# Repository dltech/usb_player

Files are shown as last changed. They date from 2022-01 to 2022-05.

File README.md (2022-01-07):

# usb_player
simple USB SD mp3 player based on stm32 MCU\
TODO:\
schematic (OK)\
board\
register defs (OK)\
RCC (OK)\
I2S PCM1754 sound out\
lm4811 power regul (OK)\
ADC sound in\
SDIO\
FAT32\
MP3 decoder\
SPI\
CC1101 4FSK\
speex build\
OTG FS USB FLASH (sd adapter)\
OTG FS USB FLASH FAT32 HOST\
STM32 DAC sound output

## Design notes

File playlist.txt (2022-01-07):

13:55:
Evanescence - Everybody's Fool
13:50:
HUDBA PRAHA - MAMA TATA
13:46:
Awolnation - Sail
13:42:
Nickelback - How You Remind Me
13:40:
Cranberries - Salvation
13:35:
Bon Jovi - Runaway
13:32:
Liam Gallagher - The River
13:27:
ZZ Top - Sharp Dressed Man (live)
13:22:
R.E.M. - Drive
13:17:
Iron Maiden - The Writing On The Wall
13:13:
TRI SESTRY - DO KOTLE NA FOTBAL
13:09:
Papa_Roach - Periscope
13:05:
Hollywood Undead - Day Of The Dead
13:02:
Rammstein - Wo Bist Du
12:56:
Republica - Ready To Go
12:52:
Faith No More - Last Cup Of Sorrow
12:48:
Red Hot Chili Peppers - Aeroplane
12:44:
LUCIE - OHEN
12:37:
Metallica - Until It Sleeps
12:33:
Hole - Malibu
12:29:
Smashing Pumpkins - Tonight,Tonight (live)
12:26:
Green Day - Redundant
12:22:
Ugly Kid Joe - Everything About You
12:16:
LOU FANANEK HAGEN & ALKEHOL - DEJVICE
12:12:
Alice Cooper - It's Me
12:07:
Marilyn Manson - Sweet Dreams
12:04:
Cranberries - Promises
11:56:
Apocalyptica - Life Burns!
11:52:
IMODIUM - VALERIE
11:48:
J.A.R. - KNIHOVNICKA
11:42:
Bon Jovi - You Give Love A Bad Name
11:38:
Red Sun Rising - Deathwish
11:31:
Foo Fighters - Everlong (live)
11:26:
Sting - All This Time
11:23:
Rise Against - Talking To Ourselves
11:16:
Soundgarden - Black Hole Sun
11:11:
Soundgarden - Black Rain
11:08:
WOHNOUT - BARBIE SONG
11:04:
Lenny Kravitz - Bring It On
10:56:
Aerosmith - Girls Of Summer
10:53:
Rammstein - Du Hast
10:49:
Red Hot Chili Peppers - Look Around
10:46:
Counting Crows - Accidentally In Love
10:40:
Metallica - Wherever I May Roam
10:35:
ZZ Top - La Grande
10:31:
P.O.D. - Youth Of The Nation
10:25:
Gossip - Standing In The Way Of Control (Live)
10:21:
Puff Daddy & Jimmy Page - Come With Me
10:19:
Wolfmother - Fellin Love
10:12:
Muse - Resistance
10:09:
Sabaton - To Hell And Back
10:05:
AC/DC - Hard As A Rock
10:02:
TRI SESTRY - PUMPA
09:52:
Offspring - Original Prankster
09:48:
Cranberries - Free To Decide
09:45:
Tarja - No Bitter End
09:42:
Green Day - Holiday
09:37:
Alice Cooper - School's Out
09:33:
Scott Stapp - Gone Too Soon
09:27:
Black Sabbath - Electric Funeral (live)
09:24:
Guano Apes - Lords Of The Boards
09:21:
Sting - Rushing Water
09:15:
VISACI ZAMEK - ZNAMKA PUNKU
09:12:
VISACI ZAMEK - NOTORIKOVA OMLUVA
09:08:
Foster The People - Pumped Up Kicks
09:04:
Rammstein - Haifisch
08:57:
System Of A Down - Lonely Day
08:53:
Nirvana - All Apologies
08:49:
U2 - Beautiful Day
08:46:
KABAT - BRUCE WILLIS
08:40:
Queen - I Want It All
08:36:
Stone Sour - Song # 3
08:31:
Alanis Morissette - Hand In My Pocket (live)
08:25:
R.E.M. - Man On The Moon
08:21:
Danko Jones - Ship of Lies
08:16:
SUPPORT LESBIENS - Sweet Little Something
08:12:
Rise Against - Satellite
08:08:
Lenny Kravitz - Fly Away
08:05:
Linkin Park - Leave Out All The Rest
07:56:
Seether - Remedy
07:54:
Faith No More - Easy....
07:47:
Bon Jovi - Bed Of Roses
07:42:
Clash - Should I Stay Or Should I Go
07:39:
WOHNOUT - MISS MARINGOTKA
07:32:
Avenged Sevenfold - Hail To The King (live)
07:26:
Guns N'Roses - You Could Be Mine
07:22:
Sixx:A.M. - The First 21
07:17:
Blink 182 - I Miss You
07:12:
Alter Bridge - Addicted To Pain
07:08:
Scorpions - White Dove
07:04:
Vanilla Sky - Umbrella
06:55:
Foo Fighters - Best Of You
06:51:
LUCIE - ČERNÍ ANDĚLÉ
06:48:
Placebo - Too Many Friends
06:45:
Offspring - Hit That
06:39:
Sex Pistols - Anarchy In The U.K.
06:35:
IMODIUM - VASEN
06:30:
U2 - Pride (In The Name Of Love) (live)
06:27:
Deaf Heart - Smells Like Cash
06:23:
AC/DC - Are You Ready
06:20:
Maneskin - I Wanna Be Your Slave
06:14:
HIM - Join Me
06:11:
Sabaton - Resist And Bite
06:08:
Bad Religion - Punk Rock Song
06:05:
Red Hot Chili Peppers - Tell Me Baby
05:56:
KABÁT - COLORADO
05:53:
Bon Jovi - Saturday Night Gave Me Sunday Morning
05:49:
Black Veil Brides - Torch
05:45:
Lenny Kravitz - Again
05:40:
Metallica - Whiskey In The Jar
05:35:
Def Leppard - Pour Some Sugar On Me
05:31:
Nickelback - Must Be Nice
05:27:
Jeff Healey Band - Stuck In The Middle With You (live)
05:21:
Guns N'Roses - Knockin' On Heaven's Door
05:18:
WOHNOUT - RAYDA
05:15:
Billy Idol - Rita Hayworth
05:10:
Green Day - Oh Love
05:06:
Aerosmith - Cryin'
05:03:
Bloodhound Gang - Foxtrot Uniform Charlie Kilo
04:55:
Moby - Why Does My Heart Feel So Bad
04:50:
Within Temptation & Tarja - Paradise (What About Us?)
04:47:
Coldplay - People of the Pride
04:42:
My Chemical Romance - Welcome To The Black Parade
04:38:
Sheryl Crow - Everyday Is A Winding Road
04:35:
Jefferson Airplane - Somebody To Love
04:32:
SKWOR - POKRIVENEJ POHLED
04:28:
Korn & Amy Lee - Freak On A Leash (live)
04:22:
Pearl Jam - Alive
04:18:
Placebo - Special Needs
04:16:
Volbeat - Wait A Minute My Girl
04:12:
Disturbed - The Sound Of Silence
04:07:
Ozzy Osbourne - Perry Mason
04:04:
Linkin Park - What I've Done
03:58:
HIM - The Funeral Hearts
03:54:
Garbage - I Think I'm Paranoid
03:51:
Korpiklaani - Rauta
03:47:
You Me At Six - Adrenaline
03:45:
HORKYZE SLIZE - A JA SPROSTA
03:40:
U2 - Staring At The Sun
03:36:
Guns N'Roses - Welcome To The Jungle
03:32:
Rise Against - The Violence
03:30:
Queen - Bicycle Race (live)
03:27:
VLTAVA - MARX,ENGELS,BEATLES
03:21:
Red Hot Chili Peppers - Snow (Hey Oh)
03:16:
Iron Maiden - The Writing On The Wall
03:12:
Foo Fighters - The Feast And The Famine
03:08:
Verve - Sonnet
03:05:
Simple Plan - Shut Up
02:57:
Alanis Morissette - You Oughta Know
02:53:
Shinedown - Cut The Cord
02:48:
Pretty Reckless - Only Love Can Save Me Now
02:45:
Chad Kroeger & Josey Scott - Hero
02:41:
Rammstein - Rammstein
02:37:
Aerosmith - Dream On
02:34:
Alice Cooper - Social Debris
02:27:
Bon Jovi - Keep The Faith (live)
02:23:
Iggy Pop & Kate Pierson - Candy
02:19:
Johnny Cash - Hurt
02:15:
Lee Aaron - C´mon
02:10:
Tarja - Falling Awake
02:07:
WANASTOWI VJECY - BLBA
02:04:
Killers - Somebody Told Me
01:57:
Hinder - Use Me
01:53:
Beck - Loser
01:50:
Halestorm - Amen
01:46:
Garbage - No Gods No Masters
01:42:
SKWOR - POHLEDY STUDENY
01:39:
Pearl Jam - Last Kiss
01:35:
Survivor - Eye Of Tiger
01:31:
Black Veil Brides - The Last One
01:26:
Awolnation - Not Your Fault (live)
01:21:
Scorpions - Wind Of Change
01:17:
Darkness - One Way Ticket
01:14:
Rise Against - Talking To Ourselves
01:11:
Linkin Park - Castle Of Glass
01:08:
KABÁT - LÁĎA
01:04:
Rasmus - No Fear
00:57:
Kid Rock - So Hott
00:51:
Aerosmith - Livin' On The Edge
00:48:
Korn - Rotting In Vain
00:44:
Black Label Society - Set You Free
00:41:
Green Day - American Idiot
00:35:
Oasis - Stand By Me
00:32:
Iron Maiden - Can I Play With Madness
00:28:
Alice Cooper - Paranoiac Personality
00:24:
Inxs - Never Tear Us Apart (live)
00:20:
Nirvana - Lithium
00:15:
U2 - Stuck In A Moment You Can't Get Out
00:13:
Wolfmother - Fellin Love
00:09:
Serj Tankian - Cornucopia
00:05:
Cranberries - When You're Gone
00:02:
VYPSANA FIXA - DEZOLAT

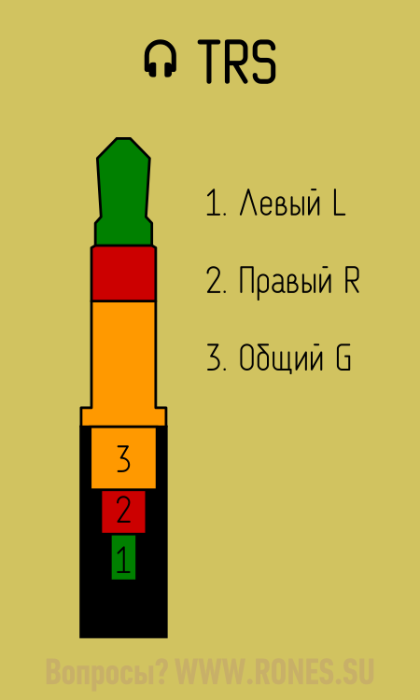
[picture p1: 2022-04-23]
pdf/TRSpinout.png

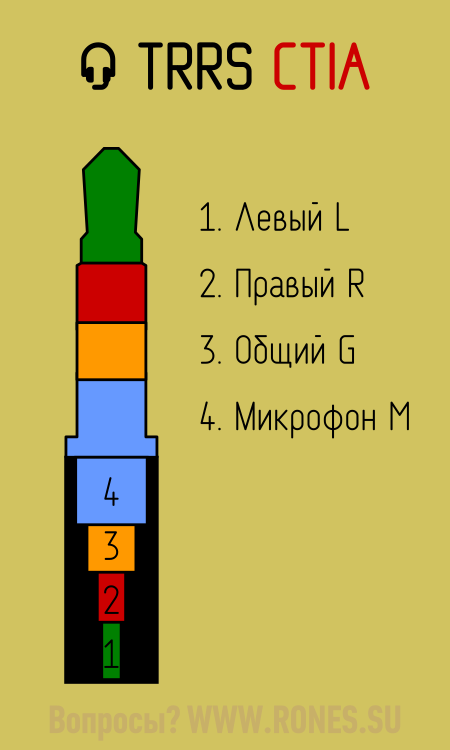
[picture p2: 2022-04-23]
pdf/TRRS_CTIA.png

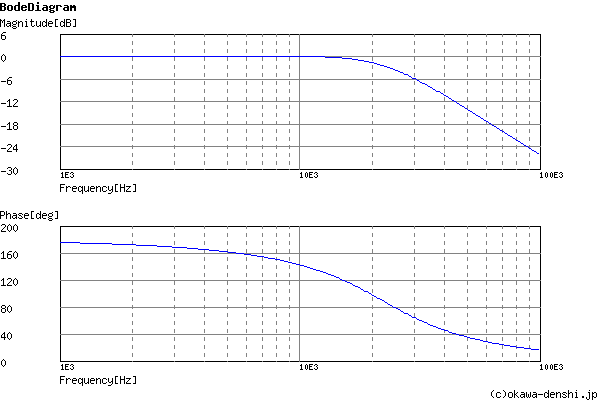
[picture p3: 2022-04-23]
pdf/low_pass.png

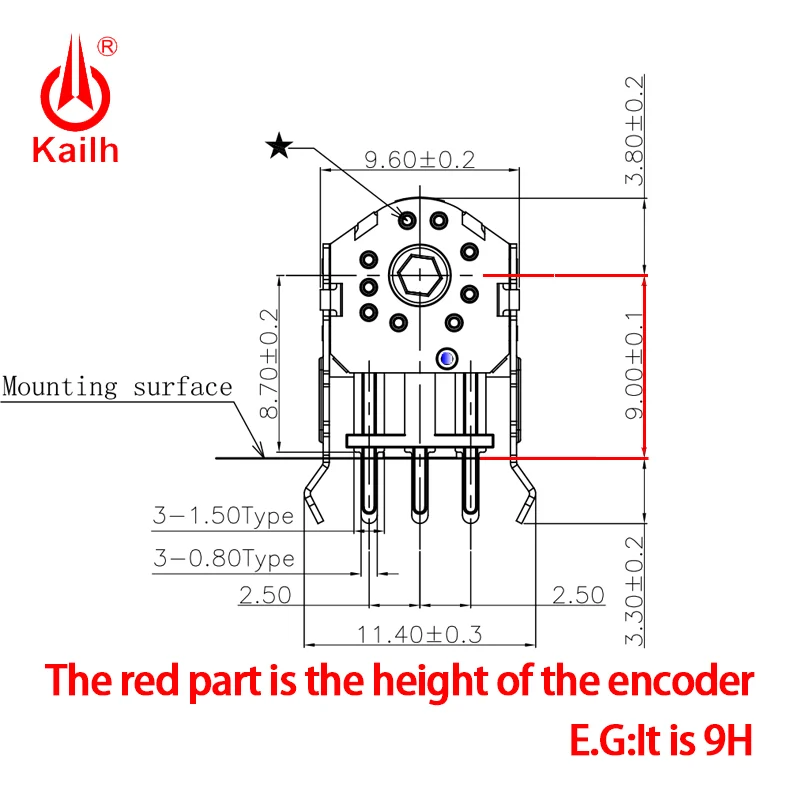
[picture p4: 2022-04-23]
pdf/mouse_encoder.webp

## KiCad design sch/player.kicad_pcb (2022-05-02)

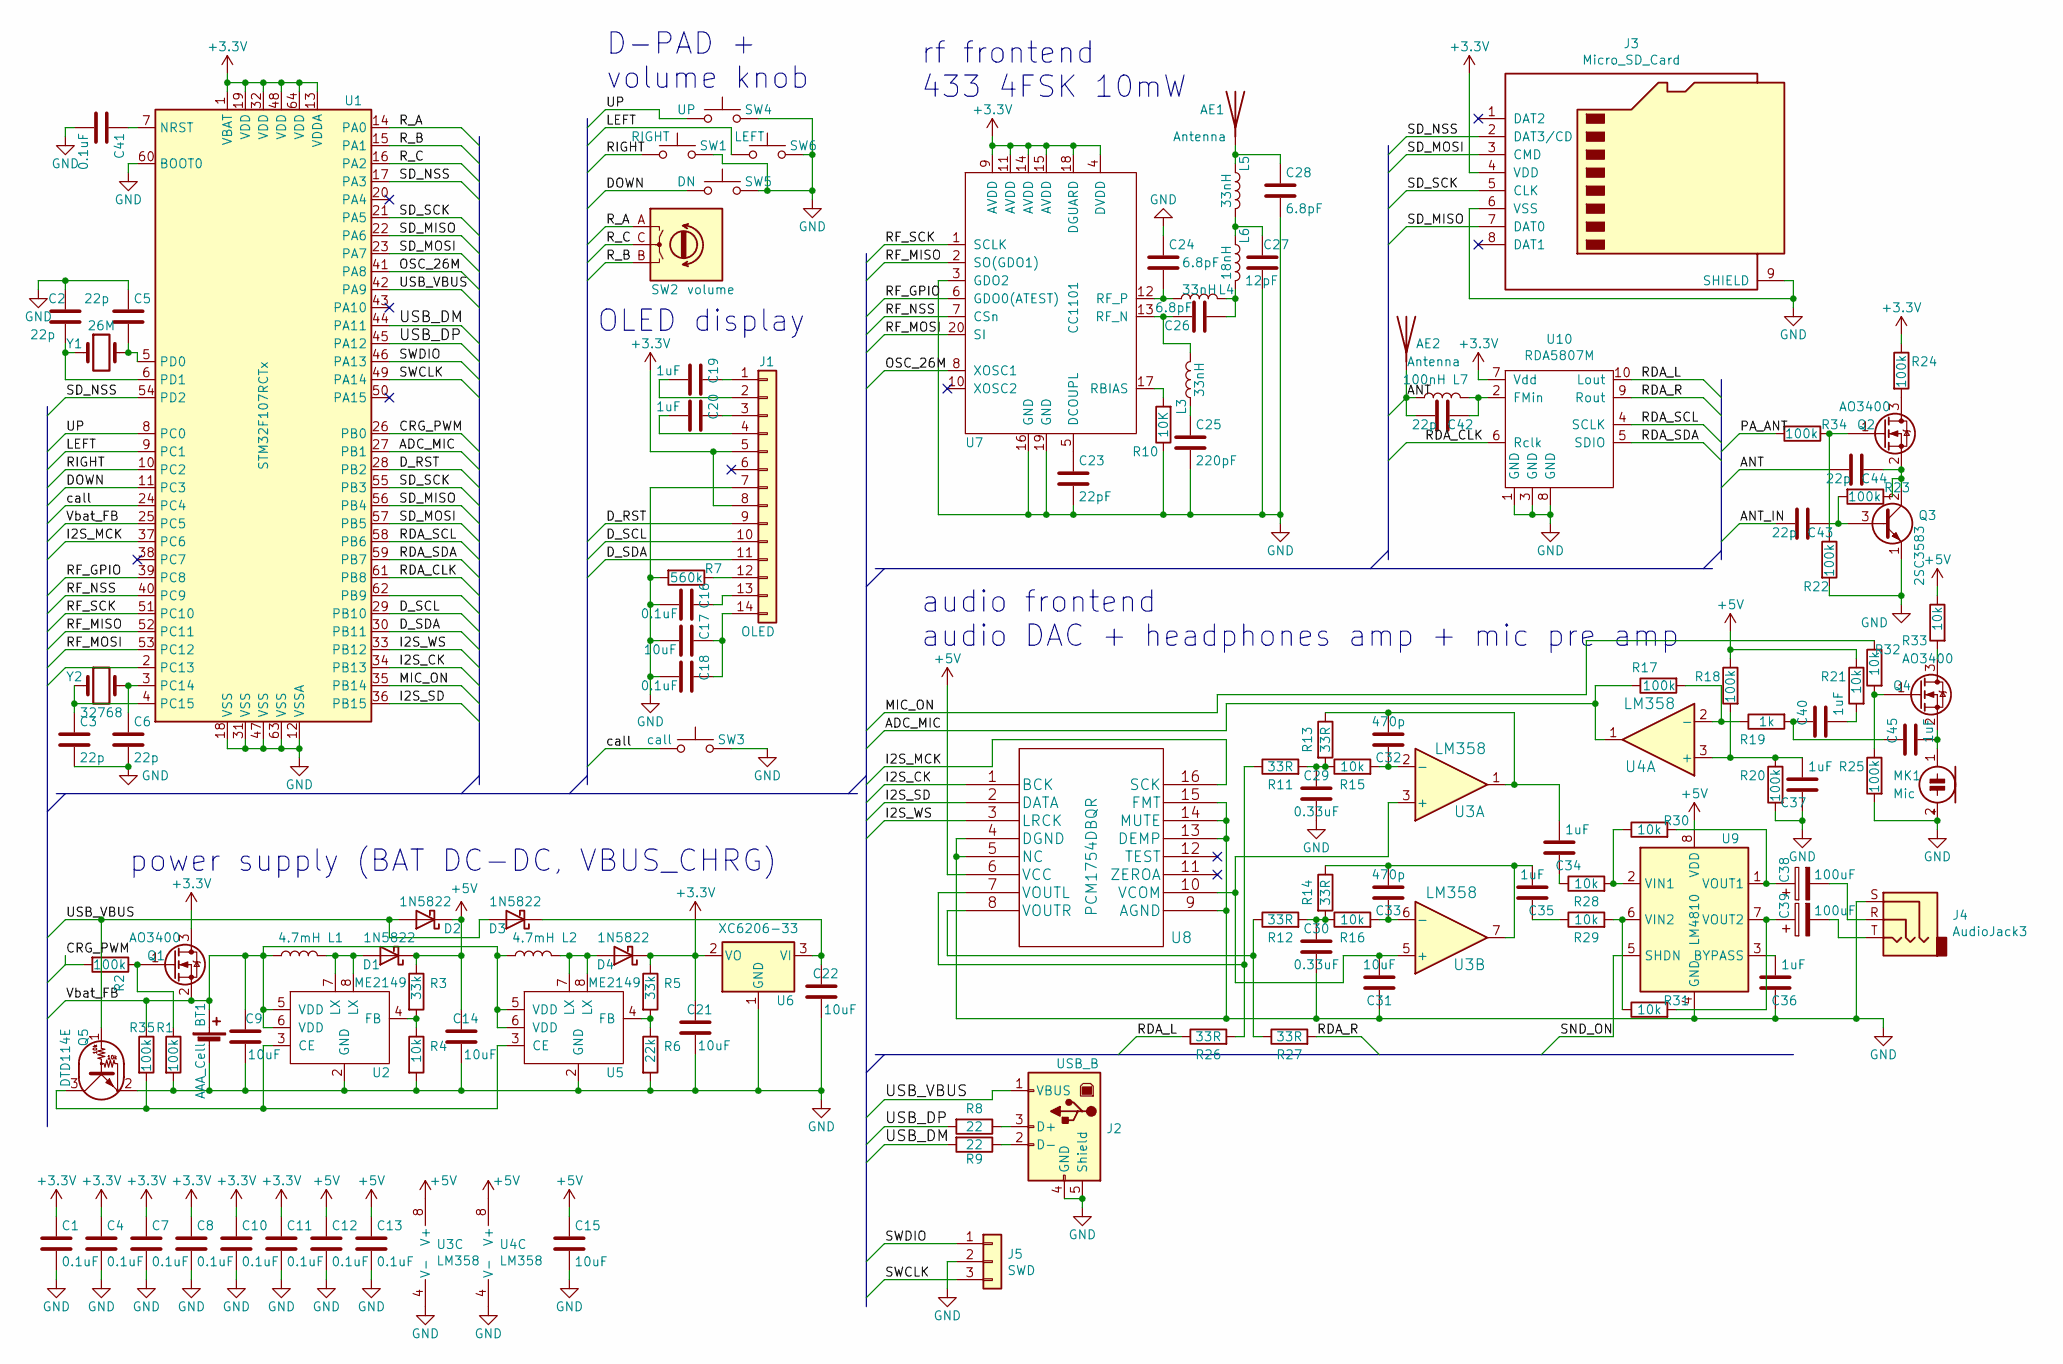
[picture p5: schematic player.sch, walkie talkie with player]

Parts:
AE1, AE2: Antenna; SolderWirePad_1x01_SMD_1x2mm
BT1: AAA_Cell; PinHeader_2x01_P2.54mm_Vertical
C1, C4, C7, C8, C10, C11, C12, C13, C16, C18, C41: 0.1uF; C_0402_1005Metric
C2, C3, C5, C6, C42, C43, C44: 22p; C_0402_1005Metric
C9, C14, C15, C17, C21, C22, C31: 10uF; C_0805_2012Metric
C19, C20, C34, C35, C36, C37, C40, C45: 1uF; C_0805_2012Metric
C23: 22pF; C_0402_1005Metric
C24, C26, C28: 6.8pF; C_0603_1608Metric
C25: 220pF; C_0603_1608Metric
C27: 12pF; C_0603_1608Metric
C29, C30: 0.33uF; C_0603_1608Metric
C32, C33: 470p; C_0603_1608Metric
C38, C39: 100uF; C_1206_3216Metric
D1, D2, D3, D4: 1N5822; D_SMA
J1: OLED; display_14p
J2: USB_B; USB_Micro-B_Molex_47346-0001
J3: Micro_SD_Card; microSD_HC_Hirose_DM3BT-DSF-PEJS
J4: AudioJack3; uefang
J5: SWD; 3WIRE_PADS
L1: 4.7mH; L_7.3x7.3_H4.5
L2: 4.7mH; L_1206_3216Metric
L3, L4, L5: 33nH; L_0603_1608Metric
L6: 18nH; L_0603_1608Metric
L7: 100nH; L_0603_1608Metric
MK1: Mic; CP_Radial_D5.0mm_P2.50mm
Q1, Q2, Q4: AO3400; SOT-23
Q3: 2SC3583; SOT-23
Q5: DTD114E; SOT-23
R1, R2, R20, R22, R23, R24, R25, R34, R35: 100k; R_0402_1005Metric
R3, R5: 33k; R_0805_2012Metric
R4, R15, R16, R21, R28, R29, R30, R31, R32, R33: 10k; R_0402_1005Metric
R6: 22k; R_0805_2012Metric
R7: 560k; R_0805_2012Metric
R8, R9: 22; R_0402_1005Metric
R10: 10K; R_0402_1005Metric
R11, R12, R13, R14, R26, R27: 33R; R_0402_1005Metric
R17, R18: 100k; C_0402_1005Metric
R19: 1k; R_0805_2012Metric
SW1: RIGHT; SW_PUSH_6mm
SW2: volume; mouse_encoder
SW3: call; SW_PUSH_6mm
SW4: UP; SW_PUSH_6mm
SW5: DN; SW_PUSH_6mm
SW6: LEFT; SW_PUSH_6mm
U1: STM32F107RCTx; LQFP-64_10x10mm_P0.5mm
U2, U5: ME2149; SSOP-8_3.9x5.05mm_P1.27mm
U3, U4: LM358; SSOP-8_3.9x5.05mm_P1.27mm
U6: XC6206-33; SOT-23
U7: CC1101; cc1101
U8: PCM1754DBQR; SSOP-16_3.9x4.9mm_P0.635mm
U9: LM4810; TSSOP-8_3x3mm_P0.65mm
U10: RDA5807M; MSOP-10_3x3mm_P0.5mm
Y1: 26M; Crystal_SMD_5032-2Pin_5.0x3.2mm
Y2: 32768; Crystal_SMD_2012-2Pin_2.0x1.2mm

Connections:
+5V: C12.1, C13.1, C14.2, C15.1, D1.1 (K), D2.1 (K), R3.1, R18.1, R21.1, R33.1, U3.8 (V+), U4.8 (V+), U8.6 (VCC), U9.8 (VDD)
/ADC_MIC: R17.1, U1.27 (PB1), U4.1
/ANT: AE2.1, C42.1, C44.1, L7.1
/ANT_IN: C43.1
/CRG_PWM: R2.2, U1.26 (PB0)
/DOWN: SW5.1, U1.11 (PC3)
/D_RST: J1.9, U1.28 (PB2)
/D_SCL: J1.10, U1.29 (PB10)
/D_SDA: J1.11, U1.30 (PB11)
/I2S_CK: U1.34 (PB13), U8.1 (BCK)
/I2S_MCK: U1.37 (PC6), U8.16 (SCK)
/I2S_SD: U1.36 (PB15), U8.2 (DATA)
/I2S_WS: U1.33 (PB12), U8.3 (LRCK)
/LEFT: SW6.1, U1.9 (PC1)
/MIC_ON: R32.1, U1.35 (PB14)
/OSC_26M: U1.41 (PA8), U7.8 (XOSC1)
/PA_ANT: R34.2
/RDA_CLK: U1.61 (PB8), U10.6 (Rclk)
/RDA_L: R26.1, U10.10 (Lout)
/RDA_R: R27.2, U10.9 (Rout)
/RDA_SCL: U1.58 (PB6), U10.4 (SCLK)
/RDA_SDA: U1.59 (PB7), U10.5 (SDIO)
/RF_GPIO: U1.39 (PC8), U7.6 (GDO0(ATEST))
/RF_MISO: U1.52 (PC11), U7.2 (SO(GDO1))
/RF_MOSI: U1.53 (PC12), U7.20 (SI)
/RF_NSS: U1.40 (PC9), U7.7 (CSn)
/RF_SCK: U1.51 (PC10), U7.1 (SCLK)
/RIGHT: SW1.1, U1.10 (PC2)
/R_A: SW2.A, U1.14 (PA0)
/R_B: SW2.B, U1.15 (PA1)
/R_C: SW2.C, U1.16 (PA2)
/SD_MISO: J3.7 (DAT0), U1.22 (PA6), U1.56 (PB4)
/SD_MOSI: J3.3 (CMD), U1.23 (PA7), U1.57 (PB5)
/SD_NSS: J3.2 (DAT3/CD), U1.17 (PA3), U1.54 (PD2)
/SD_SCK: J3.5 (CLK), U1.21 (PA5), U1.55 (PB3)
/SND_ON: U9.5 (SHDN)
/SWCLK: J5.3, U1.49 (PA14)
/SWDIO: J5.1, U1.46 (PA13)
/UP: SW4.1, U1.8 (PC0)
/USB_DM: R9.2, U1.44 (PA11)
/USB_DP: R8.2, U1.45 (PA12)
/USB_VBUS: D2.2 (A), D3.2 (A), J2.1 (VBUS), Q5.1 (B), U1.42 (PA9)
/Vbat_FB: BT1.1 (+), C9.2, L1.1, L2.1, Q1.2 (S), R35.1, U1.25 (PC5), U2.5 (VDD), U2.6 (VDD), U5.5 (VDD), U5.6 (VDD)
/call: SW3.1, U1.24 (PC4)
GND: BT1.2 (-), C1.2, C2.1, C3.2, C4.2, C5.1, C6.2, C7.2, C8.2, C9.1, C10.2, C11.2, C12.2, C13.2, C14.1, C15.2, C16.2, C17.1, C18.2, C21.1, C22.1, C23.2, C24.1, C25.2, C27.2, C28.2, C29.1, C30.1, C31.1, C36.1, C37.1, C41.2, J1.7, J2.4 (GND), J2.5 (Shield), J3.6 (VSS), J3.9 (SHIELD), J4.S, J5.2, MK1.2 (+), Q3.1 (E), Q5.2 (E), R1.2, R4.2, R6.2, R7.2, R10.1, R20.2, R22.2, R25.2, SW1.2, SW3.2, SW4.2, SW5.2, SW6.2, U1.12 (VSSA), U1.18 (VSS), U1.31 (VSS), U1.47 (VSS), U1.60 (BOOT0), U1.63 (VSS), U2.2 (GND), U3.4 (V-), U4.4 (V-), U5.2 (GND), U6.1 (GND), U7.3 (GDO2), U7.16 (GND), U7.19 (GND), U8.4 (DGND), U8.5 (NC), U8.9 (AGND), U8.13 (DEMP), U8.14 (MUTE), U8.15 (FMT), U9.4 (GND), U10.1 (GND), U10.3 (GND), U10.8 (GND)
unnamed: AE1.1, C28.1, L5.1
unnamed: C2.2, U1.6 (PD1), Y1.1
unnamed: C3.1, U1.4 (PC15), Y2.1
unnamed: C5.2, U1.5 (PD0), Y1.2
unnamed: C6.1, U1.3 (PC14), Y2.2
unnamed: C16.1, J1.13
unnamed: C17.2, C18.1, J1.14
unnamed: C19.1, J1.1
unnamed: C19.2, J1.2
unnamed: C20.1, J1.3
unnamed: C20.2, J1.4
unnamed: C23.1, U7.5 (DCOUPL)
unnamed: C24.2, L4.1, U7.12 (RF_P)
unnamed: C25.1, L3.1
unnamed: C26.1, L4.2, L6.2
unnamed: C26.2, L3.2, U7.13 (RF_N)
unnamed: C27.1, L5.2, L6.1
unnamed: C29.2, R11.2, R13.2, R15.1
unnamed: C30.2, R12.2, R14.2, R16.1
unnamed: C31.2, U3.3 (+), U3.5 (+), U8.10 (VCOM)
unnamed: C32.1, R15.2, U3.2 (-)
unnamed: C32.2, C34.2, R13.1, U3.1
unnamed: C33.1, R16.2, U3.6 (-)
unnamed: C33.2, C35.2, R14.1, U3.7
unnamed: C34.1, R28.1
unnamed: C35.1, R29.1
unnamed: C36.2, U9.3 (BYPASS)
unnamed: C37.2, R18.2, R20.1, U4.3 (+)
unnamed: C38.1, R30.2, U9.1 (VOUT1)
unnamed: C38.2, J4.R
unnamed: C39.1, R31.2, U9.7 (VOUT2)
unnamed: C39.2, J4.T
unnamed: C40.1, C45.1, R19.2
unnamed: C40.2, R21.2
unnamed: C41.1, U1.7 (NRST)
unnamed: C42.2, L7.2, U10.2 (FMin)
unnamed: C43.2, Q3.3 (B), R23.2
unnamed: C44.2, Q2.2 (S), Q3.2 (C), R23.1
unnamed: C45.2, MK1.1 (-), Q4.2 (S)
unnamed: D1.2 (A), L1.2, U2.7 (LX), U2.8 (LX)
unnamed: D4.2 (A), L2.2, U5.7 (LX), U5.8 (LX)
unnamed: J1.12, R7.1
unnamed: J2.2 (D-), R9.1
unnamed: J2.3 (D+), R8.1
unnamed: Q1.1 (G), R1.1, R2.1
unnamed: Q2.1 (G), R22.1, R34.1
unnamed: Q2.3 (D), R24.2
unnamed: Q4.1 (G), R25.1, R32.2
unnamed: Q4.3 (D), R33.2
unnamed: Q5.3 (C), R35.2, U2.3 (CE), U5.3 (CE)
unnamed: R3.2, R4.1, U2.4 (FB)
unnamed: R5.2, R6.1, U5.4 (FB)
unnamed: R10.2, U7.17 (RBIAS)
unnamed: R11.1, R26.2, U8.7 (VOUTL)
unnamed: R12.1, R27.1, U8.8 (VOUTR)
unnamed: R17.2, R19.1, U4.2 (-)
unnamed: R28.2, R30.1, U9.2 (VIN1)
unnamed: R29.2, R31.1, U9.6 (VIN2)

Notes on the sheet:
rf frontend 433 4FSK 10mW
audio frontend audio DAC + headphones amp + mic pre amp
D-PAD + volume knob
OLED display
power supply (BAT DC-DC, VBUS_CHRG)

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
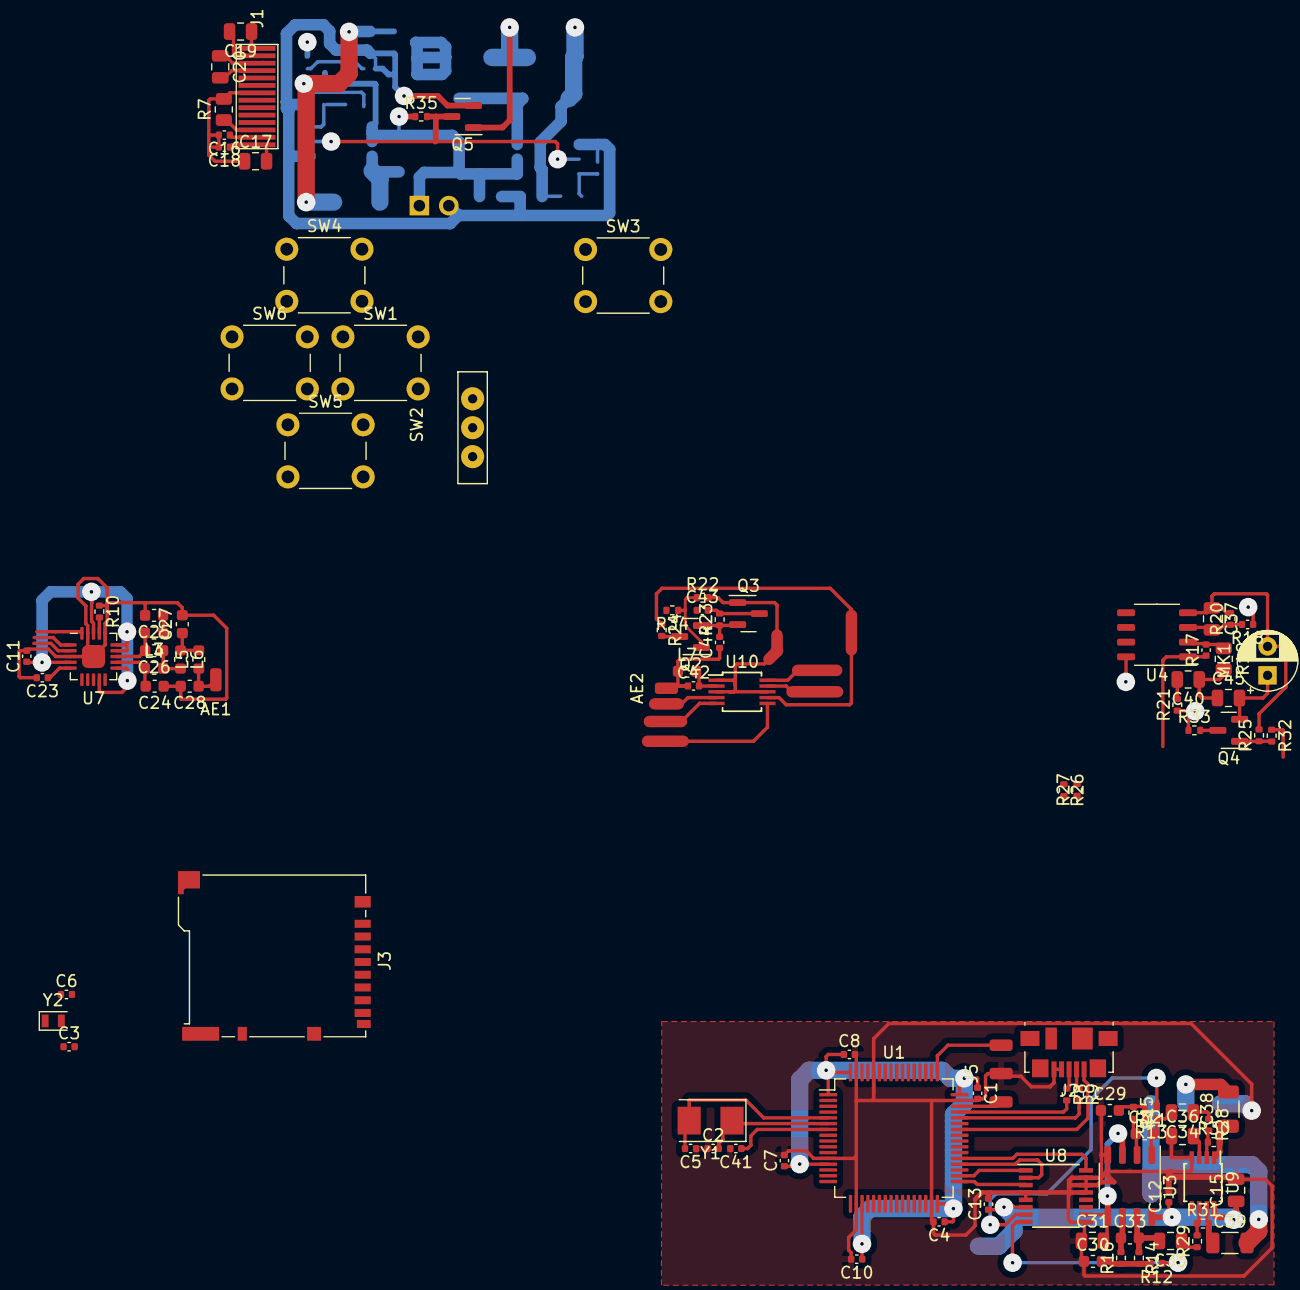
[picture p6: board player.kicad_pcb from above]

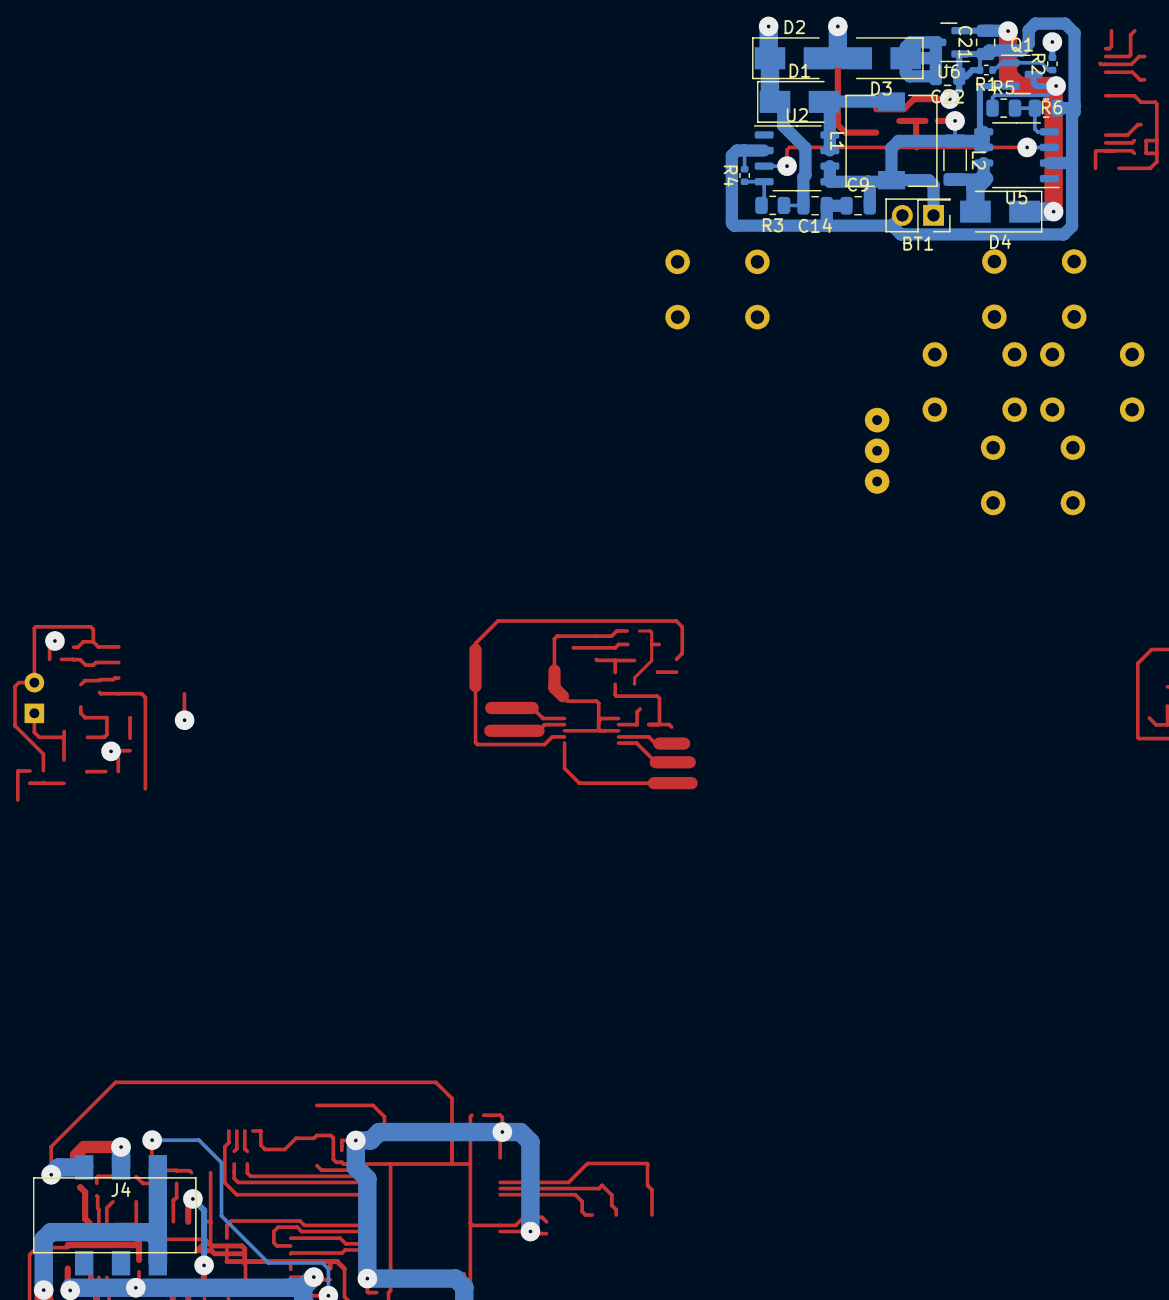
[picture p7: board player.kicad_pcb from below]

Board: 2 copper layers, 123 parts (22 on the bottom side), 102 nets.

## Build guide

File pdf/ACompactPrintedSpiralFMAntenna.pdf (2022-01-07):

See discussions, stats, and author profiles for this publication at: https://www.researchgate.net/publication/277016433
A Compact Printed Spiral FM Antenna (https://www.researchgate.net/publication/277016433_A_Compact_Printed_Spiral_FM_Antenna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)

Conference Paper · July 2015

CITATION
1

READS
4,141

### 4 authors, including:

Some of the authors of this publication are also working on these related projects:

WiFi Communication/Networking View project (https://www.researchgate.net/project/WiFi-Communication-Networking?el=1_x_9&_esc=publicationCoverPdf)

On-chip antenna design, optimization and fabrication in 28nm CMOS technology for 5G communication systems View project (https://www.researchgate.net/project/On-chip-antenna-design-optimization-and-fabrication-in-28nm-CMOS-technology-for-5G-communication-systems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)

Abraham Loutridis (https://www.researchgate.net/profile/Abraham-Loutridis?el=1_x_5&_esc=publicationCoverPdf)
AlpsAlpine Europe

### 15 PUBLICATIONS 71 CITATIONS

SEE PROFILE (https://www.researchgate.net/profile/Abraham-Loutridis?el=1_x_7&_esc=publicationCoverPdf)

Kansheng Yang (https://www.researchgate.net/profile/Kansheng-Yang?el=1_x_5&_esc=publicationCoverPdf)
The Antenna Company Nederland

### 17 PUBLICATIONS 113 CITATIONS

SEE PROFILE (https://www.researchgate.net/profile/Kansheng-Yang?el=1_x_7&_esc=publicationCoverPdf)

M.J. Ammann (https://www.researchgate.net/profile/Mj-Ammann?el=1_x_5&_esc=publicationCoverPdf)
Technological University Dublin - City Campus (https://www.researchgate.net/institution/Technological-University-Dublin-City-Campus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)

295 PUBLICATIONS 5,004 CITATIONS

SEE PROFILE (https://www.researchgate.net/profile/Mj-Ammann?el=1_x_7&_esc=publicationCoverPdf)

All content following this page was uploaded by Abraham Loutridis (https://www.researchgate.net/profile/Abraham-Loutridis?el=1_x_10&_esc=publicationCoverPdf) on 22 May 2015.

The user has requested enhancement of the downloaded file.

1

A Compact Printed Spiral FM Antenna

Abraham Loutridis¹, 2

, Kansheng Yang¹, 2

, Matthias John²

, and Max Ammann¹
1Antenna & HF Research Centre, Dublin Institute of Technology, Dublin 8, Ireland 2CTVR — The Telecommunications Research Centre, Trinity College Dublin, Dublin 2, Ireland

Abstract— In this work,a compact printed spiral monopole antenna operating in the FM frequency band (88–108 MHz) is reported. The antenna is printed on a 100 mm × 50 mm PCB layer providing more than 20 MHz bandwidth at −2 dB threshold and is easily fabricated with low manufacturing cost. The antenna was also measured and simulated on 900 mm × 900 mm ground plane which is representative of a vehicle roof

### 1. INTRODUCTION

Electrically Small Antennas (ESAs) are desired and essential for many applications and especially at lower frequencies such as in the HF and VHF bands. Nowadays, compact antennas have become standard for radio receivers on vehicles and mobile terminals which lead to new requirements for small, efficient and low cost designs. Good performance of a radio receiver is heavily depended on the antenna performance. A variety of FM antenna types have been reported for automotive and portable applications including, active [1] and short meander line monopoles [2], fractal Hilbert curve antenna [3], chip antennas [4], window-printed active antennas [5] and the shark type antennas [6].
The frequency range for the FM radio band which defined from FCC regulation is from 88 MHz to 108 MHz and the respective wavelength λ0 for the centre frequency f0 = 98 MHz is around 3 meters. The height of a quarter wavelength FM monopole antenna is around 750 mm. In order to reduce the size of the monopoles, helix antennas with a height of 80 mm are used for FM radio receivers. In this paper a compact spiraled monopole antenna is reported with an overall volume of 100 mm × 50 mm × 1.5 mm. A five element network matching circuit is embedded in orderto increase the bandwidth to more than 20 MHz. The antenna can be easily integrated into compact volumes, is low cost and easily fabricated.

### 2. COMPACT SPIRAL ANTENNA

The antenna was designed and printed on a 100 mm × 50 mm double sided FR-4 substrate (εr = 4.3, tan δ = 0.025, thickness = 1.5 mm) with copper metallization thickness of 0.035 mm (Figure 1(a)). The 67.9 mm × 50 mm metal ground plane is on the rear of the same PCB board. The antenna is fed by a 50 Ω microstrip line of 3 mm width which is connected to a SMA connector. The miniaturization is based on its spiral structure occupying a 33 mm (0.01λ0) × 50 mm (0.02λ0) area on the PCB board (Figure 1(c)). In order to improve the antenna bandwidth, a five element π-matching network circuit (Figure 1(b)) is added so that the impedance bandwidth of antenna can be wider, covering the frequency range of 31.5 MHz bandwidth at VSWR 8.5 : 1 (Figure 2). As shown in Figure 1(b) the matching network consists of two parallel capacitors of 68 pF and 82 pF, two serial inductors of 100 nH and 1.5 nH and a parallel inductor of 68 nH.

### 3. SIMULATED & MEASURED RESULTS

Figure 2 illustrates the measured S11 results of the final model and the simulated S11 results of the antenna with and without the matching network. The measurements were obtained using a Rohde & Schwarz ZVA 40 vector network analyzer. For the simulation model without the matching network the antenna resonates at 102.9 MHz with a −2 dB impedance bandwidth of 6.3 MHz. For the antenna with the matching network the simulation results indicate a −2 dB impedance bandwidth of 22.3 MHz (86.2–108.5 MHz), while for the measured design the impedance bandwidth at −2 dB threshold is 31.5 MHz (76.8–108.3 MHz).
The antenna was also measured and simulated on 900 mm × 900 mm ground plane which is representative of a vehicle roof (Figure 3). The spiral monopole (33 mm × 50 mm) is located on a metallic ground plane while the other part of the antenna with the microstrip line is located

2

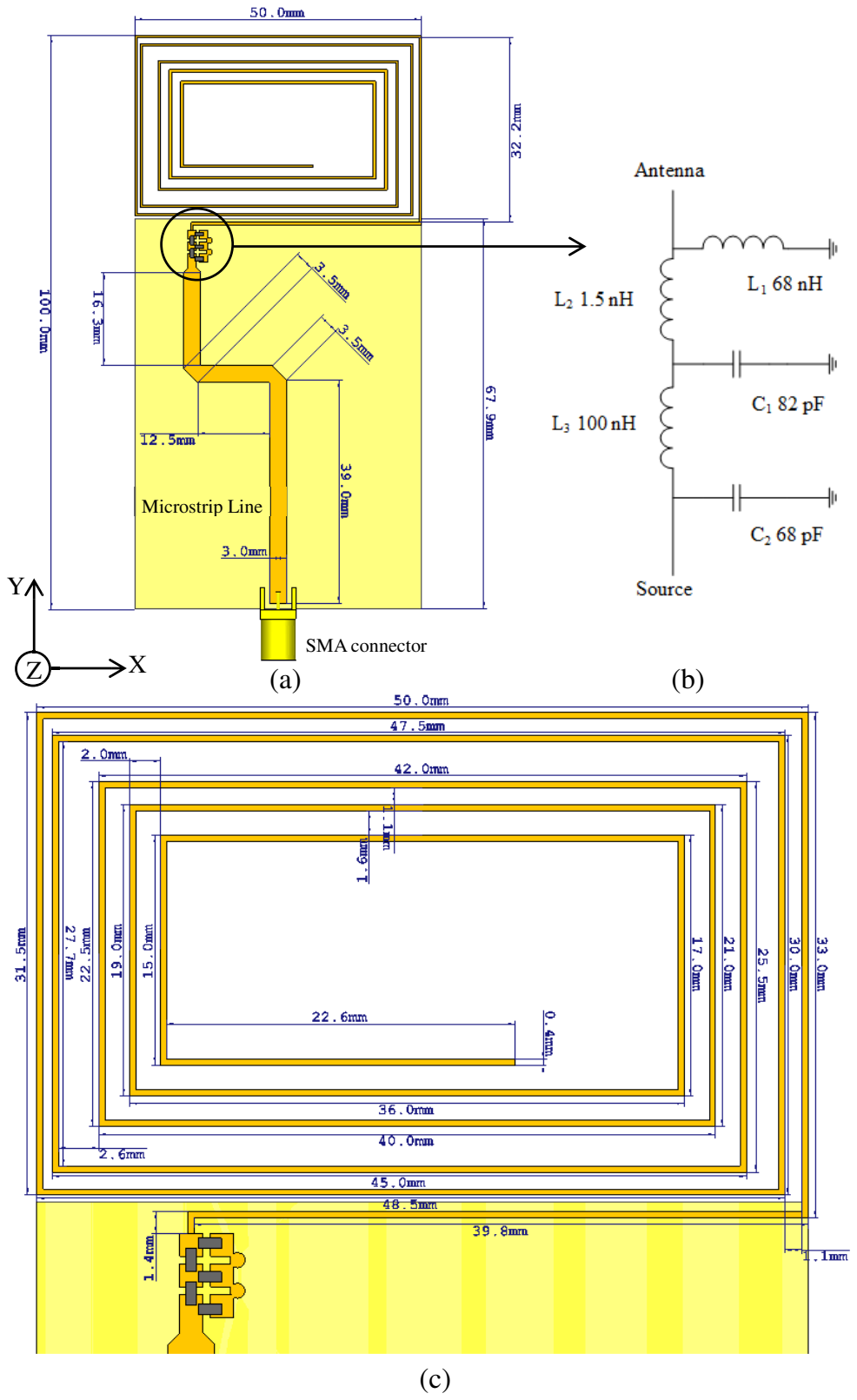
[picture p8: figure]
Microstrip Line; SMA connector

Figure 1: (a) Antenna general view, (b) π-matching network, (c) spiral monopole.

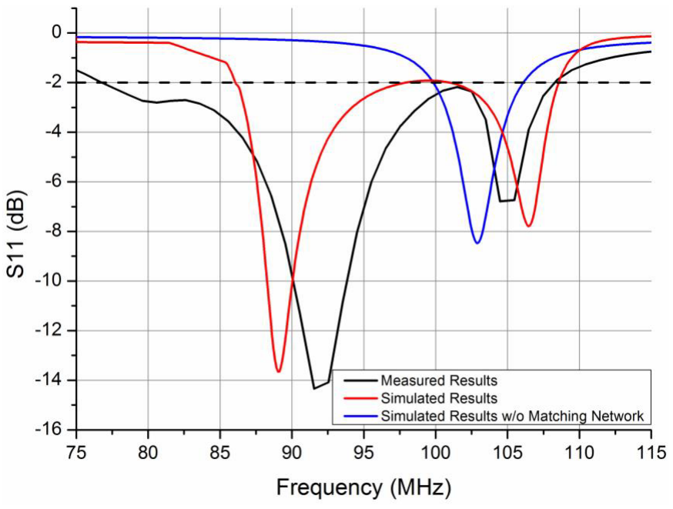
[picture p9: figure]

Figure 2: Simulated and measured S11 results.

below it. In Figure 4 the simulated and measured results are depicted. The antenna resonates at 91.5 MHz with a −2 dB bandwidth of 30.5 MHz (77.3–107.8 MHz) which is compared to the results in Figure 2. The simulated results provide a −2 dB bandwidth of 18 MHz (83–101 MHz).
In Figure 5 the simulated z-x and x-y plane radiation patterns at 98 MHz are illustrated.

3

900 mm

900 mm

GND

Monopole | 33 mm

50 mm

Figure 3: The FM antenna on large ground plane.

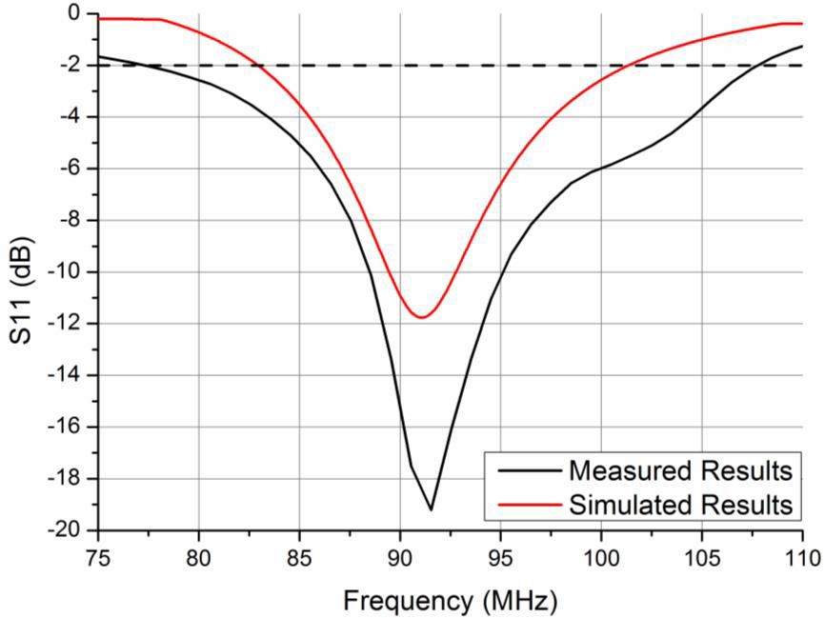
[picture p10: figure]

Figure 4: Simulated and measured results with the antenna on a large ground plane.

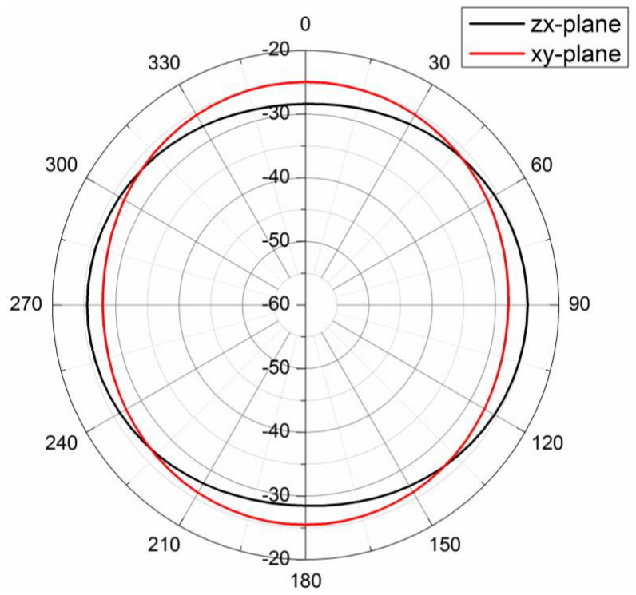
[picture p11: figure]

Figure 5: The simulated Phi (ϕ) components for the zx and xy-plane at 98 MHz.

The patterns are illustrated both in 10 dB/division scaled plot. The Phi (ϕ) component provides omnidirectional characteristics in both planes. The simulated maximum realized gain and total efficiency is −24.9 dBi and 2% at 98 MHz respectively.

### 4. CONCLUSIONS

In this work, a compact spiral FM monopole antenna is described. The proposed antenna is an electrically small antenna (< 0.037λ0) offering a 32% fractional bandwidth (−2 dB) over the centre frequency (f0 = 98 MHz) and covers the whole FM frequency band (88 MHz–108 MHz). The antenna is low cost, easily fabricated with omnidirectional radiation characteristics suitable to embed into housing. The antenna still operates with a decent wide bandwidth on large sized ground plane which makes it usable for automotive and vehicle applications.

REFERENCES
1. Negut, A., L. Reiter, J. Hopf, and S. Lindenmeier, “Performance of a 20 cm short active AM/FM monopole antenna for automotive application,” IEEE European Conference on Antennas and Propagation (EuCAP), 2009.
2. Perri, E. B. and S. Forcellini, “Very short meander monopole antennas,” IEEE Antennas and Propagation Society International Symposium AP-S, 2008.
3. Borja, C., J. Anguera, C. Puente, and J. Verg´es, “How much can be reduced the internal FM antenna of mobiles phones,” IEEE European Conference on Antennas and Propagation (EuCAP), 2010.
4. Song, S.-M., L. Jin, Y. Zheng, and G.-Q. Yang, “A miniaturized FM chip antennas for handset devices,” International Workshop on Microwave and Millimeter Wave Circuits and System Technology (MMWCST), 2012.
5. Schaffner, J. H., H. J. Song, A. Bekaryan, H.-P. Hsu, M. Wisnewski, and J. Graham, “The impact of vehicle structural components on radiation patterns of a window glass embedded FM antenna,” IEEE Transactions on Antennas and Propagation, Vol. 59, No. 10, 3536–3543, 2011.
6. Chang, D.-C., F.-Y. Lin, B.-H. Zeng, and J. Chen, “Compact size antenna for car FM radio,” PIERS Proceedings, 223–224, Taipei, Mar. 25–28, 2013.

View publication stats

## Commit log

2021-10-14 template for stm32f107
2021-10-15 spi/i2s registers
2021-10-15 i2c regs
2021-10-23 adc and dac regs
2021-10-23 dma regs, for player all regs complete
2021-12-06 config 1101, almost
    [1101 calc.ods, player.kicad_pcb, player.sch]
2021-12-22 schematic add
    [player.sch]
2021-12-22 freq calc verified with SmartRF
    [player.sch]
2021-12-23 mic add, rf433
    [player.sch]
2021-12-25 schematic almost complete
    [player.sch]
2021-12-27 5807 FM sch add
    [player.sch]
2022-01-07 sch ok
    [player.sch]
2022-04-14 rda registers
    [player.kicad_pcb, player.sch]
2022-04-23 add micro and audio checked
    [player.kicad_pcb, player.sch]
2022-04-24 soundcard test board
    [player.kicad_pcb, player_4pin.sch]
2022-05-02 sound front end scenario
    [player.kicad_pcb, player.sch]
